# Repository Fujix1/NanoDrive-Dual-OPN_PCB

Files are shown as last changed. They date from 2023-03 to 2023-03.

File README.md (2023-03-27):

# NanoDrive-Dual-OPN_PCB
PCB of NanoDrive Dual OPN for KiCad 7.

<br />この 作品 は <a rel="license" href="http://creativecommons.org/licenses/by-nc-sa/4.0/">クリエイティブ・コモンズ 表示 - 非営利 - 継承 4.0 国際 ライセンス</a>の下に提供されています。

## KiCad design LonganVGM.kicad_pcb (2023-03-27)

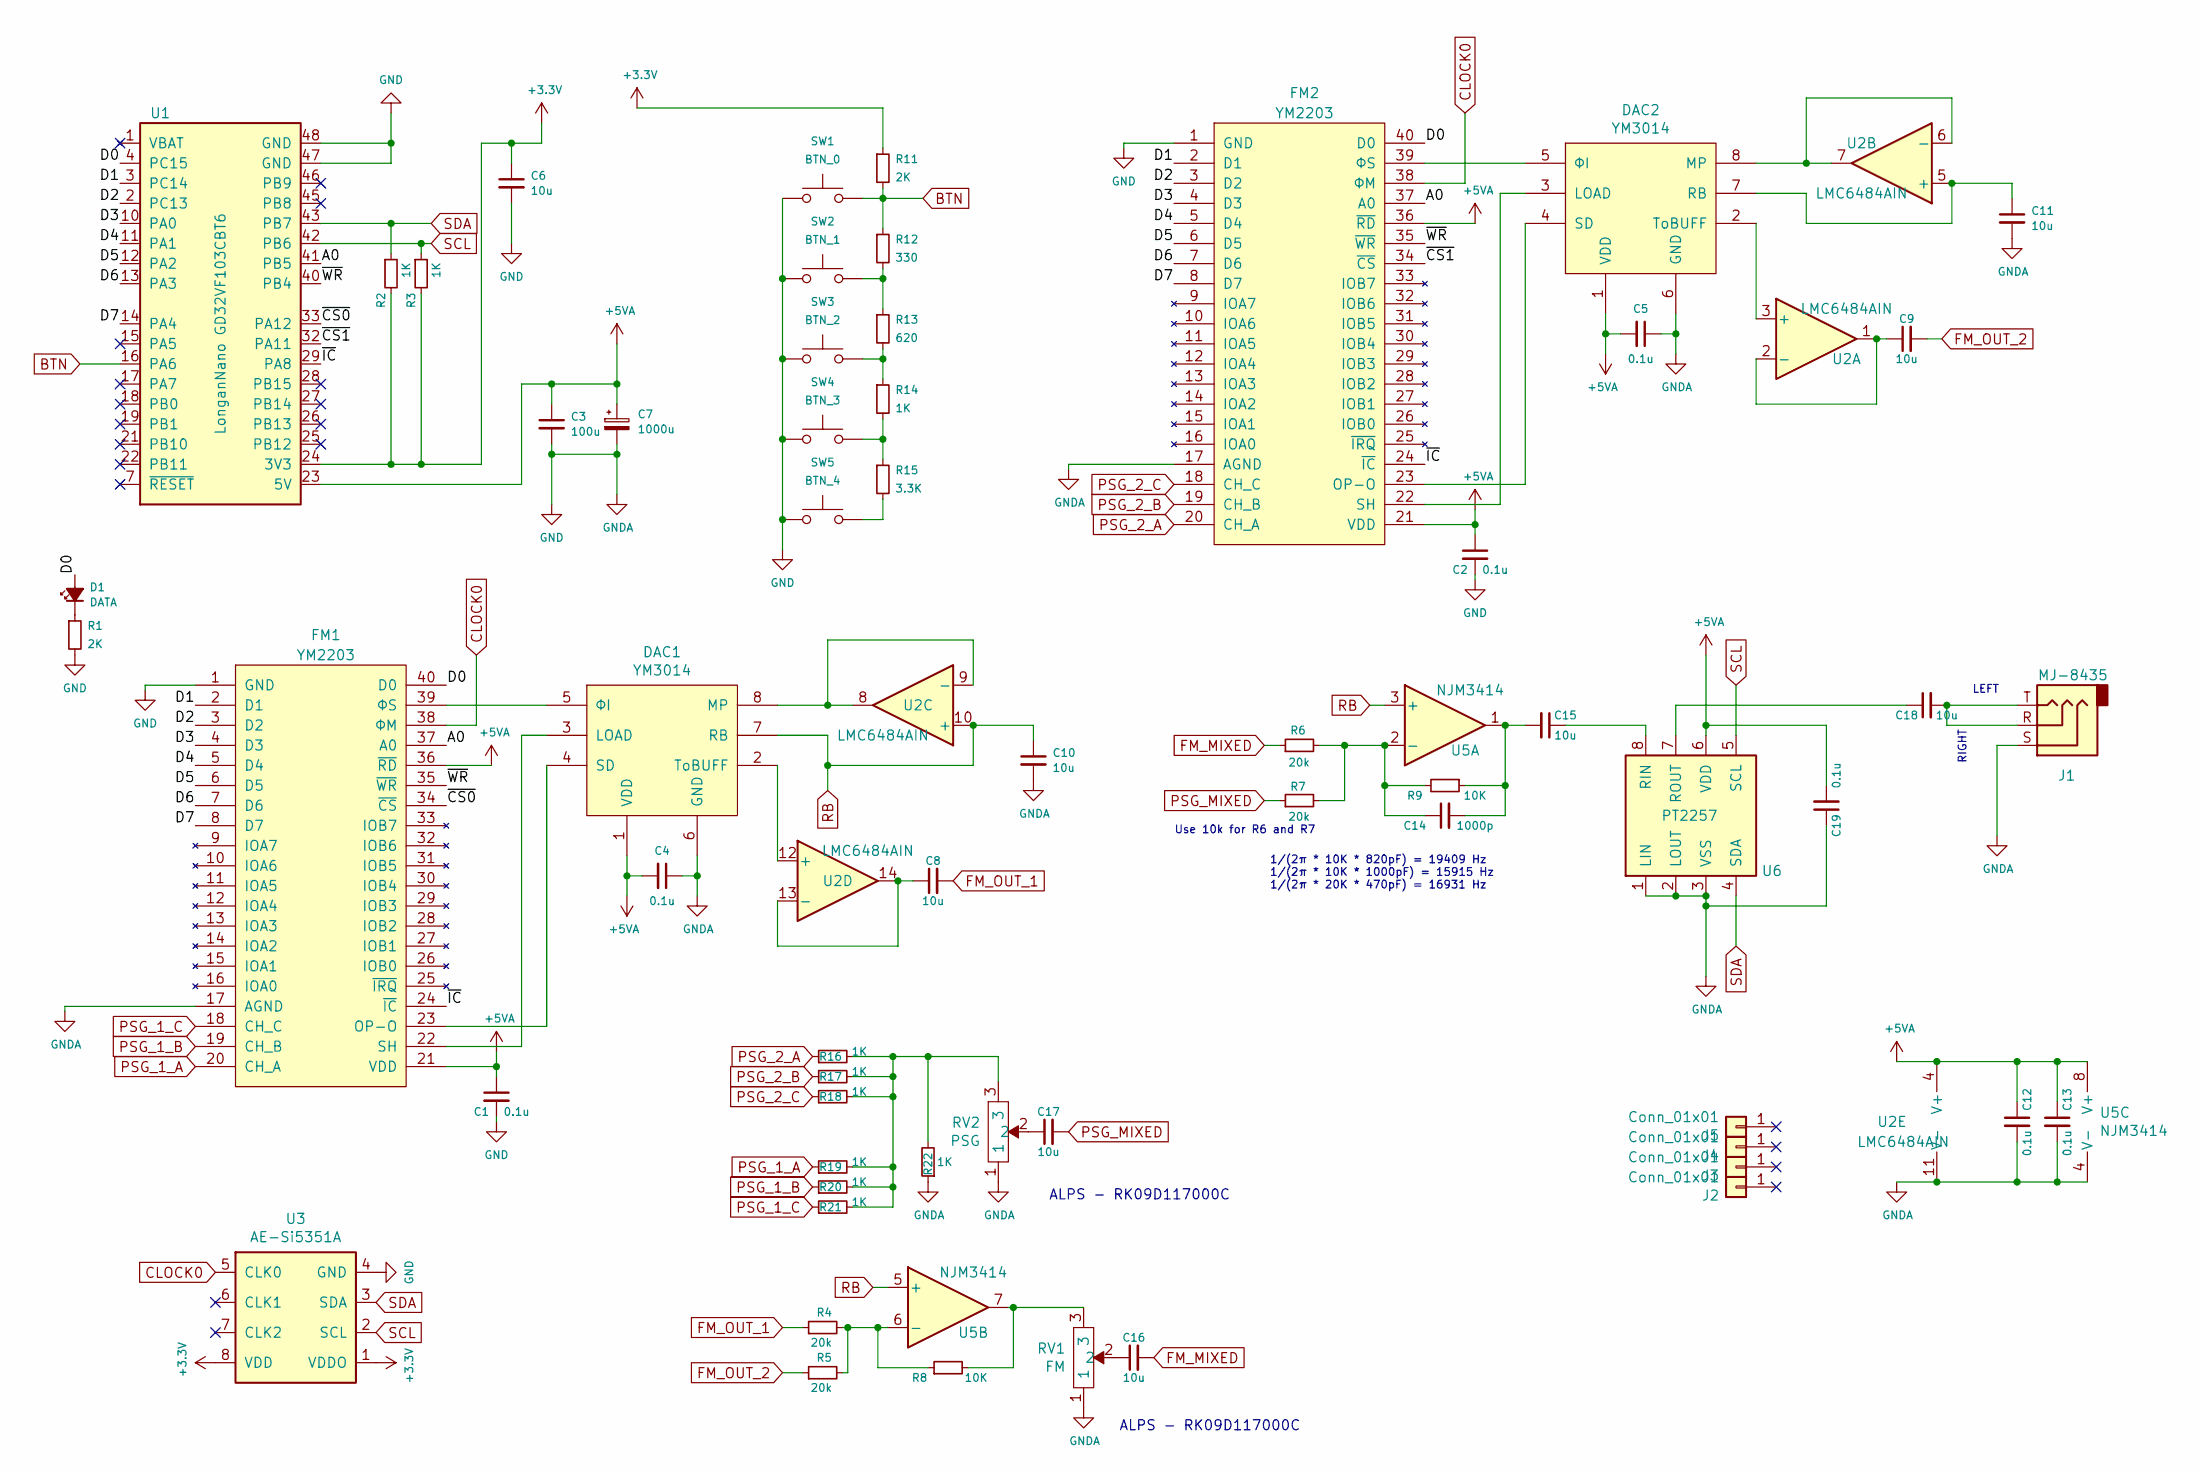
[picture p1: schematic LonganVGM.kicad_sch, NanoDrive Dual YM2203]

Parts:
C1, C2, C4, C5, C12, C13, C19: 0.1u; C_Disc_D4.3mm_W1.9mm_P5.00mm
C3: 100u; CP_Radial_D6.3mm_P2.50mm
C6, C8, C9, C10, C11, C15, C16, C17, C18: 10u; CP_Radial_D5.0mm_P2.00mm
C7: 1000u; CP_Radial_D8.0mm_P3.50mm
C14: 1000p; C_Disc_D4.3mm_W1.9mm_P5.00mm
D1: DATA; LED_D5.0mm_Clear
DAC1, DAC2: YM3014; DIP-8_W7.62mm_Socket
FM1, FM2: YM2203; DIP-40_W15.24mm_Socket
J1: MJ-8435; MJ8435
J2, J3, J4, J5: Conn_01x01; hole
R1, R11: 2K; R_Axial_DIN0207_L6.3mm_D2.5mm_P7.62mm_Horizontal
R2, R3, R14, R16, R17, R18, R19, R20, R21, R22: 1K; R_Axial_DIN0207_L6.3mm_D2.5mm_P7.62mm_Horizontal
R4, R5, R6, R7: 20k; R_Axial_DIN0207_L6.3mm_D2.5mm_P7.62mm_Horizontal
R8, R9: 10K; R_Axial_DIN0207_L6.3mm_D2.5mm_P7.62mm_Horizontal
R12: 330; R_Axial_DIN0207_L6.3mm_D2.5mm_P7.62mm_Horizontal
R13: 620; R_Axial_DIN0207_L6.3mm_D2.5mm_P7.62mm_Horizontal
R15: 3.3K; R_Axial_DIN0207_L6.3mm_D2.5mm_P7.62mm_Horizontal
RV1: FM; RK09D
RV2: PSG; RK09D
SW1: BTN_0; SW_PUSH_6mm_H4.3mm
SW2: BTN_1; SW_PUSH_6mm_H4.3mm
SW3: BTN_2; SW_PUSH_6mm_H4.3mm
SW4: BTN_3; SW_PUSH_6mm_H4.3mm
SW5: BTN_4; SW_PUSH_6mm_H4.3mm
U1: LonganNano GD32VF103CBT6; LonganNano
U2: LMC6484AIN; DIP-14_W7.62mm_Socket
U3: AE-Si5351A; DIP-8_W7.62mm_Socket
U5: NJM3414; DIP-8_W7.62mm_Socket
U6: PT2257; DIP-8_W7.62mm_Socket

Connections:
+3V3: C6.1, R2.2, R3.2, R11.1, U1.24 (3V3), U3.1 (VDDO), U3.8 (VDD)
+5VA: C1.1, C2.1, C3.1, C4.2, C5.2, C7.1, C12.1, C13.1, C19.2, DAC1.1 (VDD), DAC2.1 (VDD), FM1.21 (VDD), FM1.36 (~RD), FM2.21 (VDD), FM2.36 (~RD), U1.23 (5V), U2.4 (V+), U5.8 (V+), U6.6 (VDD)
/A0: FM1.37 (A0), FM2.37 (A0), U1.41 (PB5)
/D0: D1.2 (A), FM1.40 (D0), FM2.40 (D0), U1.4 (PC15)
/D1: FM1.2 (D1), FM2.2 (D1), U1.3 (PC14)
/D2: FM1.3 (D2), FM2.3 (D2), U1.2 (PC13)
/D3: FM1.4 (D3), FM2.4 (D3), U1.10 (PA0)
/D4: FM1.5 (D4), FM2.5 (D4), U1.11 (PA1)
/D5: FM1.6 (D5), FM2.6 (D5), U1.12 (PA2)
/D6: FM1.7 (D6), FM2.7 (D6), U1.13 (PA3)
/D7: FM1.8 (D7), FM2.8 (D7), U1.14 (PA4)
/~CS0: FM1.34 (~CS), U1.33 (PA12)
/~CS1: FM2.34 (~CS), U1.32 (PA11)
/~IC: FM1.24 (~IC), FM2.24 (~IC), U1.29 (PA8)
/~WR: FM1.35 (~WR), FM2.35 (~WR), U1.40 (PB4)
BTN: R11.2, R12.1, SW1.2, U1.16 (PA6)
CLOCK0: FM1.38 (ΦM), FM2.38 (ΦM), U3.5 (CLK0)
FM_MIXED: C16.2, R6.1
FM_OUT_1: C8.2, R4.1
FM_OUT_2: C9.2, R5.1
GND: C1.2, C2.2, C3.2, C4.1, C5.1, C6.2, C7.2, C10.2, C11.2, C12.2, C13.2, C19.1, DAC1.6 (GND), DAC2.6 (GND), FM1.1 (GND), FM1.17 (AGND), FM2.1 (GND), FM2.17 (AGND), J1.S, R1.2, R22.1, RV1.1, RV2.1, SW1.1, SW2.1, SW3.1, SW4.1, SW5.1, U1.47 (GND), U1.48 (GND), U2.11 (V-), U3.4 (GND), U5.4 (V-), U6.1 (LIN), U6.2 (LOUT), U6.3 (VSS)
unnamed: C8.1, U2.13 (-), U2.14
unnamed: C9.1, U2.1, U2.2 (-)
unnamed: C11.1, DAC2.7 (RB), U2.5 (+)
unnamed: C14.1, R6.2, R7.2, R9.2, U5.2 (-)
unnamed: C14.2, C15.2, R9.1, U5.1
unnamed: C15.1, U6.8 (RIN)
unnamed: C16.1, RV1.2
unnamed: C17.1, RV2.2
unnamed: C18.1, U6.7 (ROUT)
unnamed: C18.2, J1.R, J1.T
unnamed: D1.1 (K), R1.1
unnamed: DAC1.2 (ToBUFF), U2.12 (+)
unnamed: DAC1.3 (LOAD), FM1.22 (SH)
unnamed: DAC1.4 (SD), FM1.23 (OP-O)
unnamed: DAC1.5 (ΦI), FM1.39 (ΦS)
unnamed: DAC1.8 (MP), U2.8, U2.9 (-)
unnamed: DAC2.2 (ToBUFF), U2.3 (+)
unnamed: DAC2.3 (LOAD), FM2.22 (SH)
unnamed: DAC2.4 (SD), FM2.23 (OP-O)
unnamed: DAC2.5 (ΦI), FM2.39 (ΦS)
unnamed: DAC2.8 (MP), U2.6 (-), U2.7
unnamed: R4.2, R5.2, R8.1, U5.6 (-)
unnamed: R8.2, RV1.3, U5.7
unnamed: R12.2, R13.1, SW2.2
unnamed: R13.2, R14.1, SW3.2
unnamed: R14.2, R15.1, SW4.2
unnamed: R15.2, SW5.2
unnamed: R16.2, R17.2, R18.2, R19.2, R20.2, R21.2, R22.2, RV2.3
PSG_1_A: FM1.20 (CH_A), R19.1
PSG_1_B: FM1.19 (CH_B), R20.1
PSG_1_C: FM1.18 (CH_C), R21.1
PSG_2_A: FM2.20 (CH_A), R16.1
PSG_2_B: FM2.19 (CH_B), R17.1
PSG_2_C: FM2.18 (CH_C), R18.1
PSG_MIXED: C17.2, R7.1
RB: C10.1, DAC1.7 (RB), U2.10 (+), U5.3 (+), U5.5 (+)
SCL: R3.1, U1.42 (PB6), U3.2 (SCL), U6.5 (SCL)
SDA: R2.1, U1.43 (PB7), U3.3 (SDA), U6.4 (SDA)

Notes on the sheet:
ALPS - RK09D117000C
LEFT
1/(2π * 10K * 820pF) = 19409 Hz 1/(2π * 10K * 1000pF) = 15915 Hz 1/(2π * 20K * 470pF) = 16931 Hz
Use 10k for R6 and R7
RIGHT

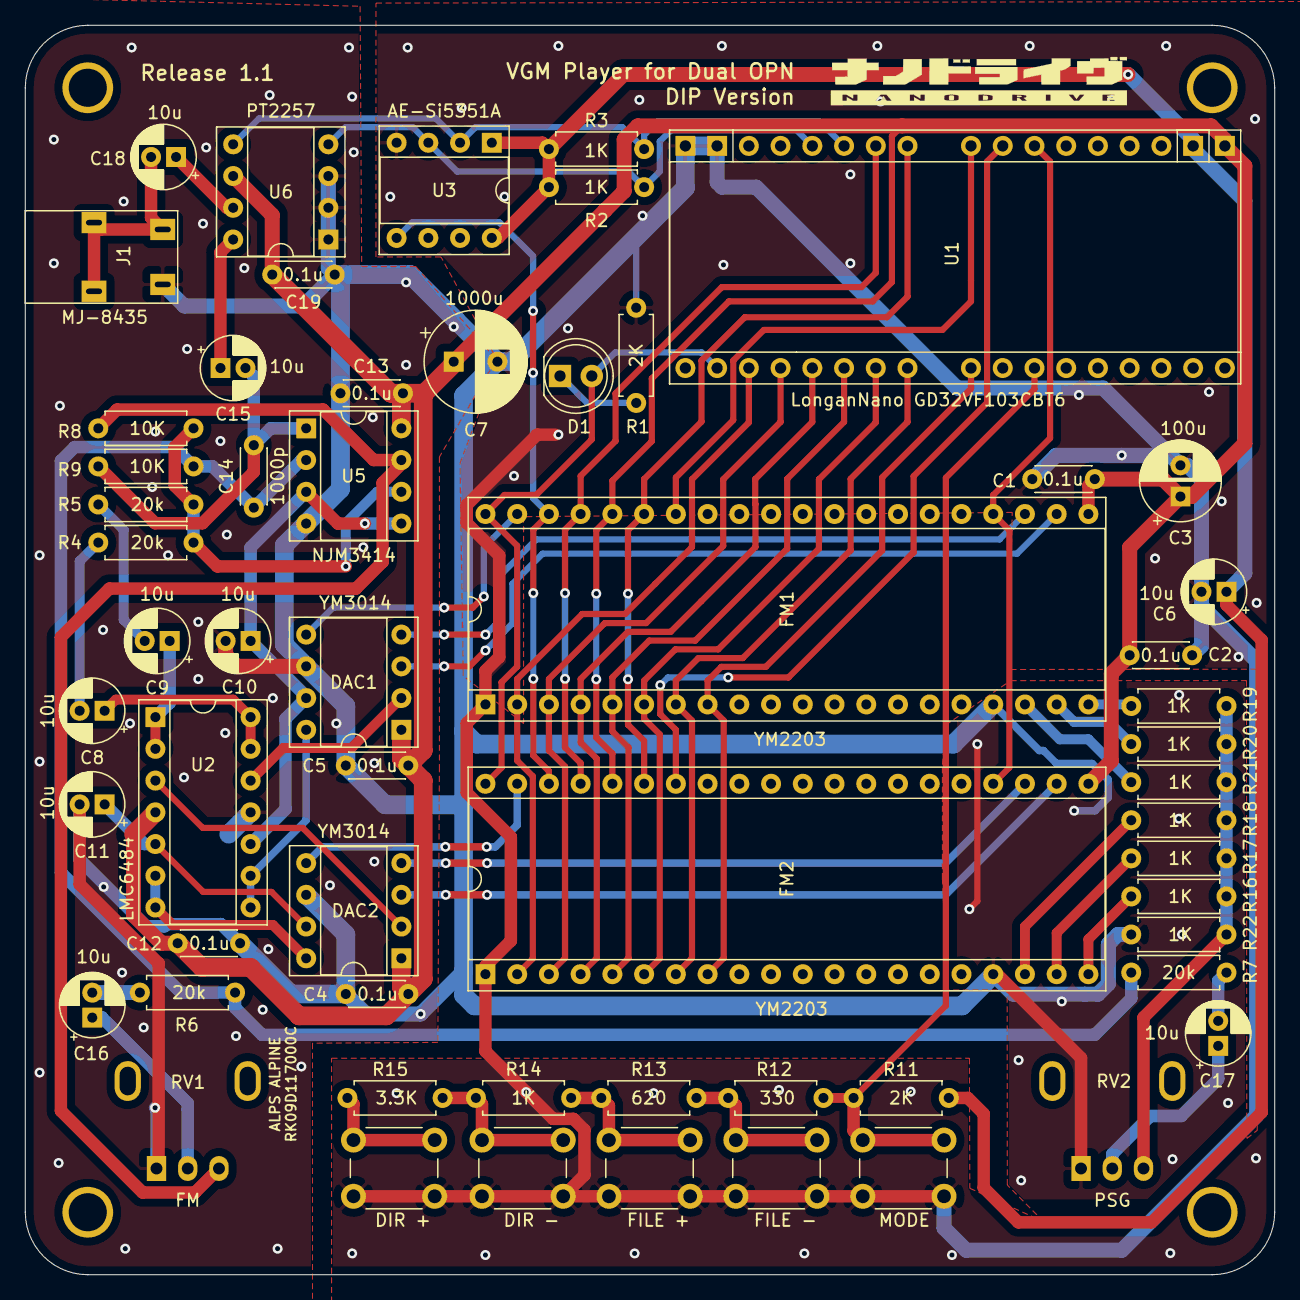
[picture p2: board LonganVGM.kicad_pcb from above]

Board: 2 copper layers, 100.0 x 100.0 mm, 62 parts (0 on the bottom side), 59 nets.

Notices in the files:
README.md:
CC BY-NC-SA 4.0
